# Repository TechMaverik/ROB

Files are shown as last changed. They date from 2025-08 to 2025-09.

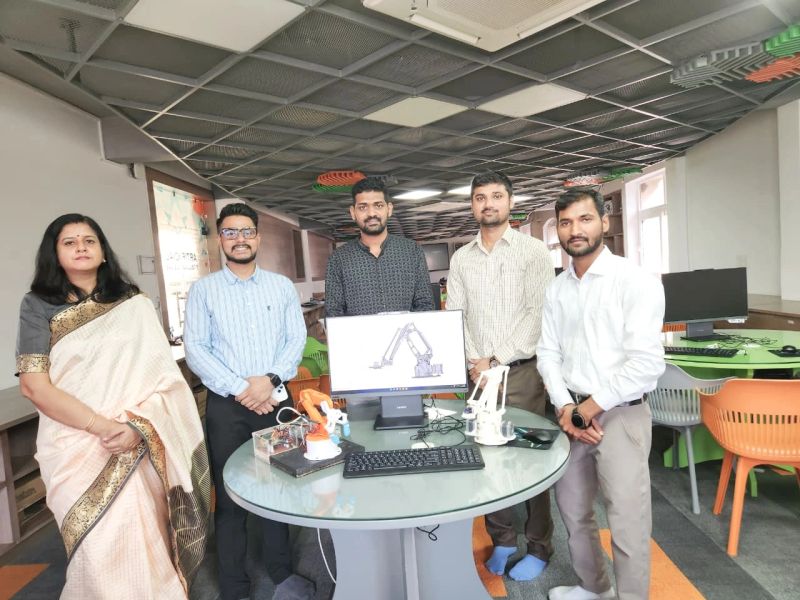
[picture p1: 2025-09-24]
static/Team.jpeg

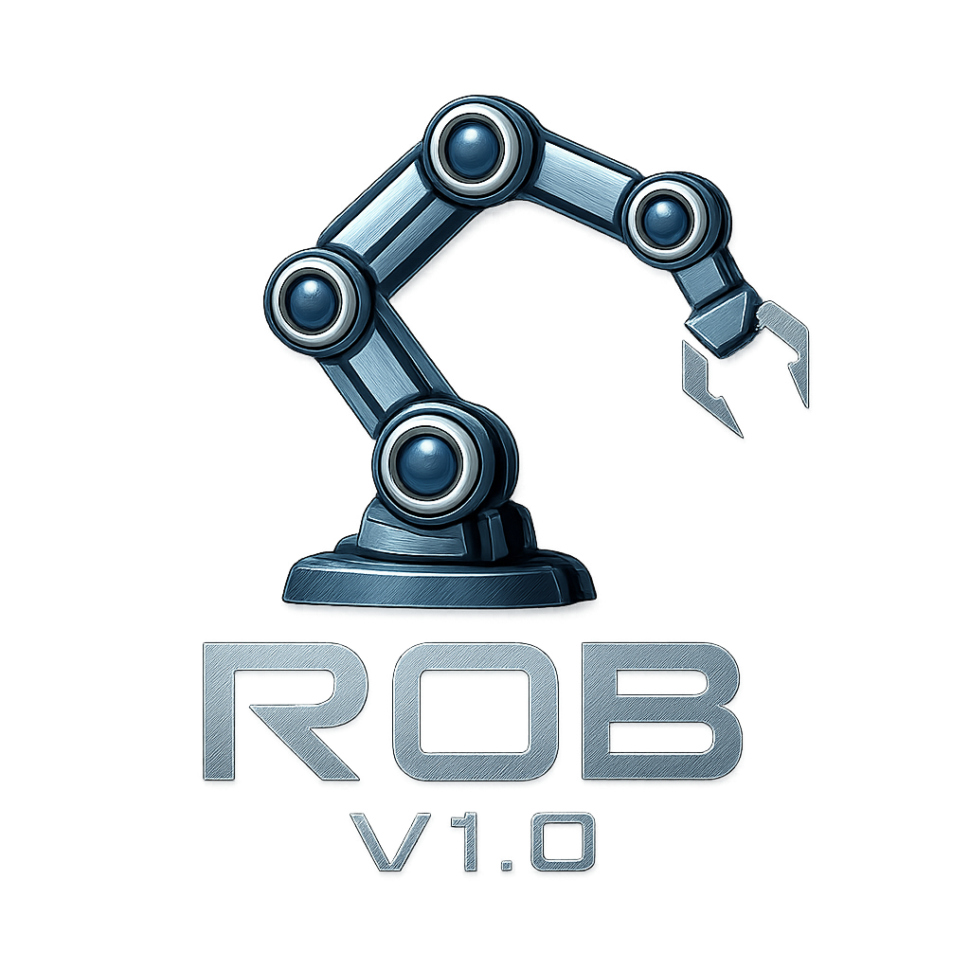
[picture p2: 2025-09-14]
static/rob.png

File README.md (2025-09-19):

# ROB - Robotics On Board
<image src="static/studio.png" height=300px width=300px></image>

The project ROB is a robotic arm developed with in-house software, hardware assembly, and custom PCB design. ROB-Studio is the software used to interact with the robot.  
Version 1.0 features a 5-degree-of-freedom robotic arm powered by 6 servo motors, capable of lifting up to 50 g of payload. ROB-Studio is made using the software framework 
called HL-Engine 3, which acts as a middleware to communicate with Hardware and Software.

## ROB version 1.0
## Components Used
1. Servo Motor MG995
2. Servo Motor SG90
3. PCA9685 Servomotor Driver
4. OLED Display 128 x 64
5. ESP32

## Firmware
The baremetal interfacing and control system code is written in Micropython for ESP32

## Procedure of connection of motors and arm pieces
1. Upload the files under Firmware Folder
2. Make sure to provide a valid SSID and Password in the code as per your network connection.
3. Connect the servo motors from channel 0 to channel 5 in order base,shoulder,elbow,wrist-pitch,wrist-yaw,pick.
4. Make sure the servo is set to 90 degress.
5. Adjust the home position according to your requirements.

## Procedure to run the ROB-Studio
1. Install python 3.10 or later version
2. Create a virtual environment called .robot using the command <code>python3 -m venv .robot</code> ( One time )
3. Now run <code> pip3 install -r requirements.txt </code> ( One time )
4. Now run <code> chmod +x ./launcher </code> ( One time )
5. <b>To run the app run ./launcher.py </b>

## Alternative steps to run ROB-Studio
1. Follow the steps till line number 3
2. Now run <code>source .rob/bin/activate </code>
3. Now run <code>python run.py</code>

## ROB Studio
<image src="static/StudioHome.png"></image>
You can control the robor arm by adjusting the slider of each joints and by pressing the Move button. Inorder to record the particular orienttation, one has to adjust the arm and press the Record Button.
<image src="static/StudioRecord.png"></image>
Your recorded operations can be seen under Record and Play tab. You can start running the application by pressing the Play button.
<image src="static/StudioDevice.png"></image>
You can connect the ROB studion to the ROB by entering the IP Address displayed on ROB OLED Display. A sample is shown above.

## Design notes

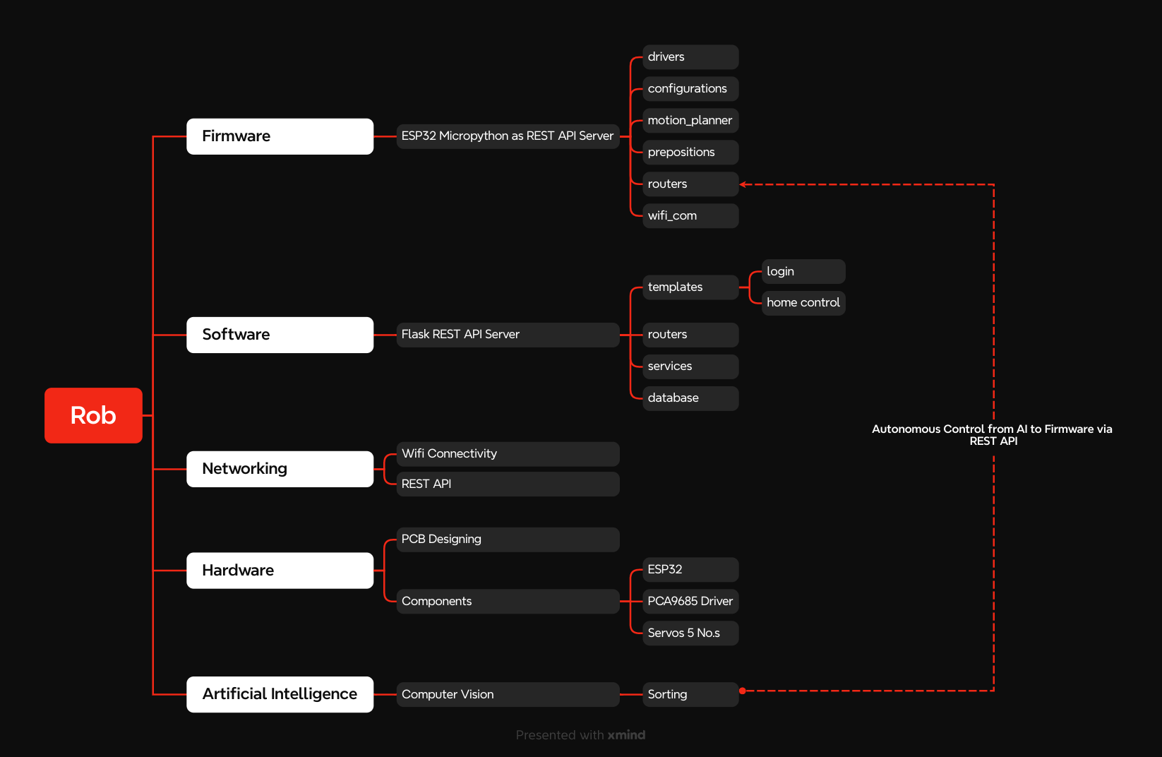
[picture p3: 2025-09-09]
Rob-Architect-Diagram.png

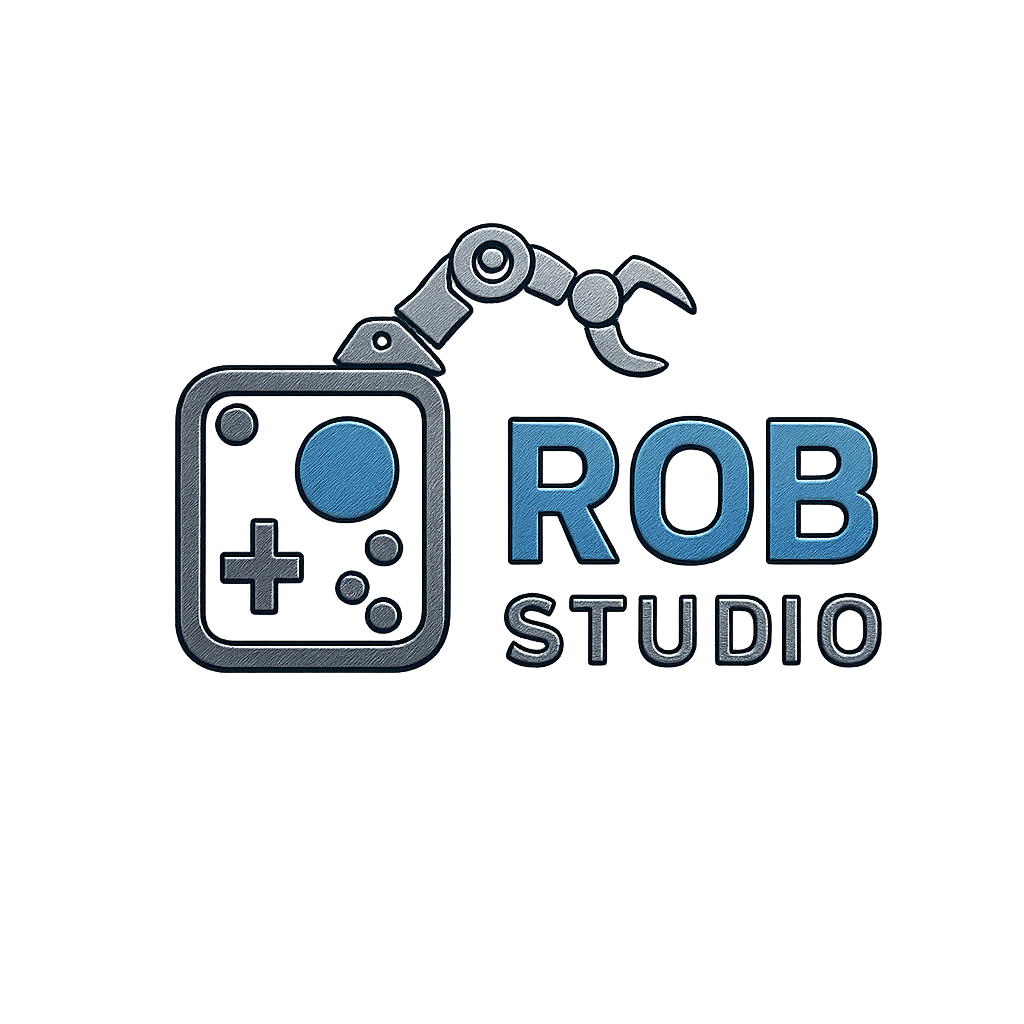
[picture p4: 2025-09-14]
static/studio.png

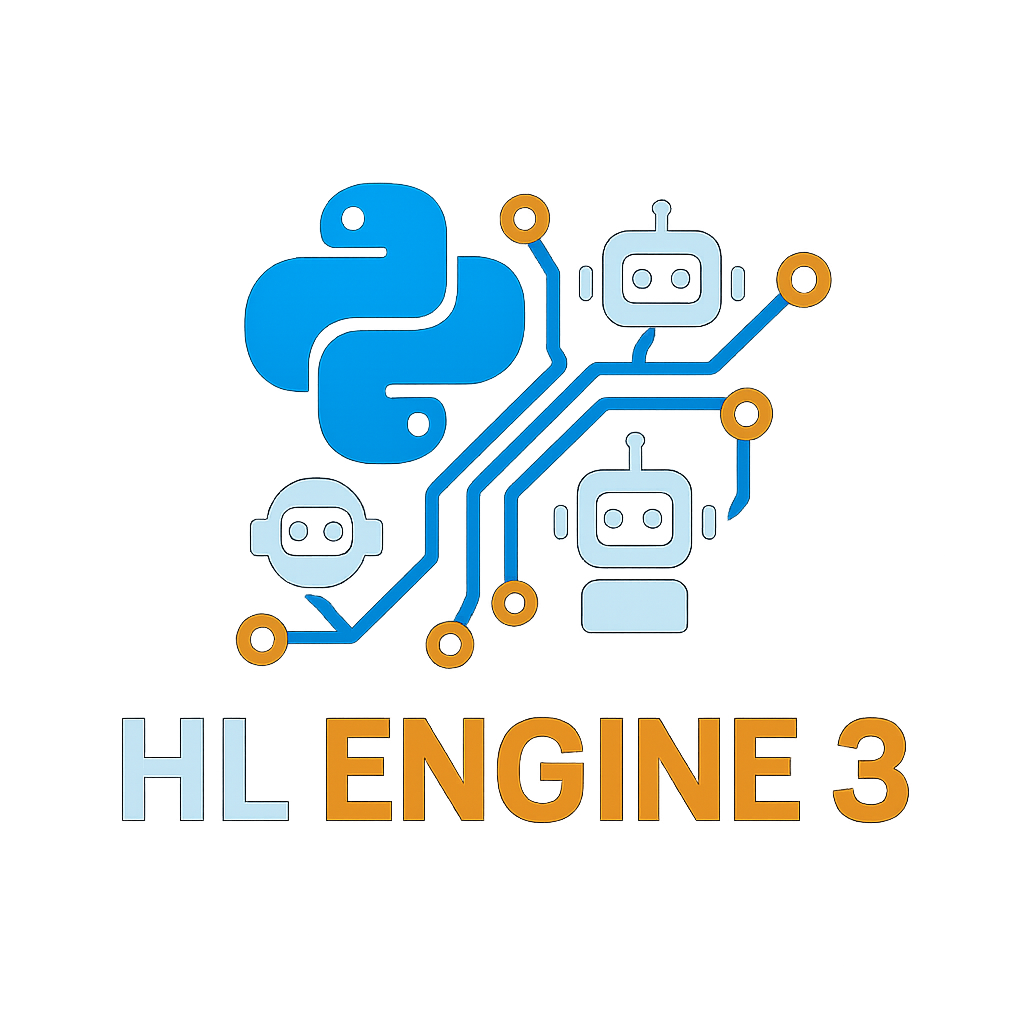
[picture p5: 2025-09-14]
static/hlengine3.png

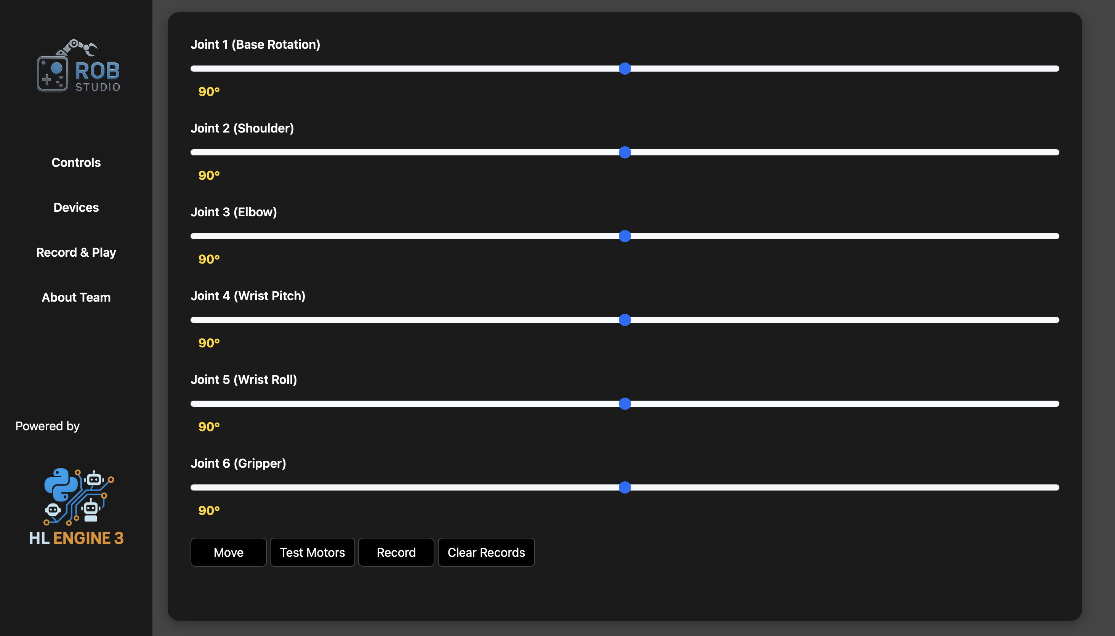
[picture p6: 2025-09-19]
static/StudioHome.png

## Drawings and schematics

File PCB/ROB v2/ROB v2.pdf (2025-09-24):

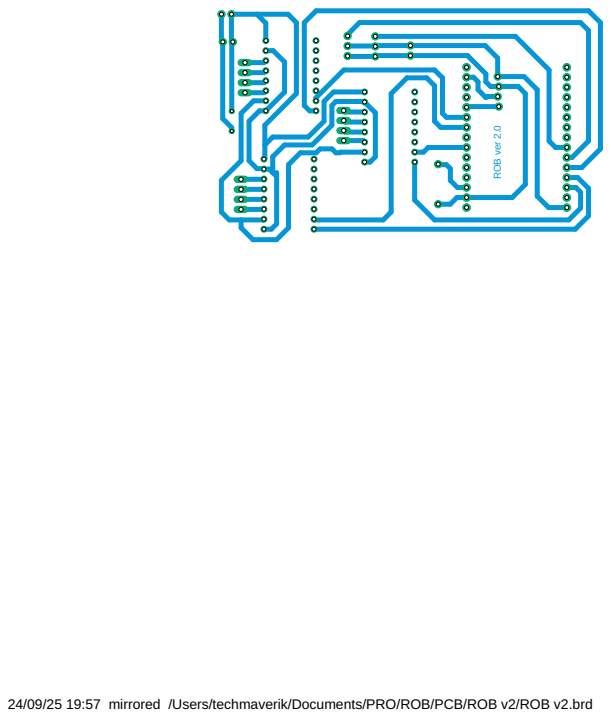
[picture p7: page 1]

24/09/25 19:57 mirrored /Users/techmaverik/Documents/PRO/ROB/PCB/ROB v2/ROB v2.brd

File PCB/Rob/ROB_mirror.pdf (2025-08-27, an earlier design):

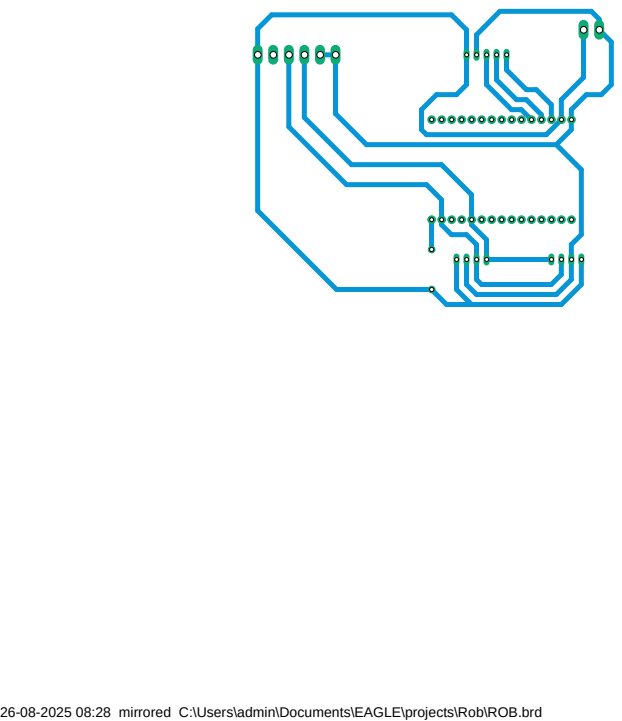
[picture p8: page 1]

26-08-2025 08:28 mirrored C:\Users\admin\Documents\EAGLE\projects\Rob\ROB.brd

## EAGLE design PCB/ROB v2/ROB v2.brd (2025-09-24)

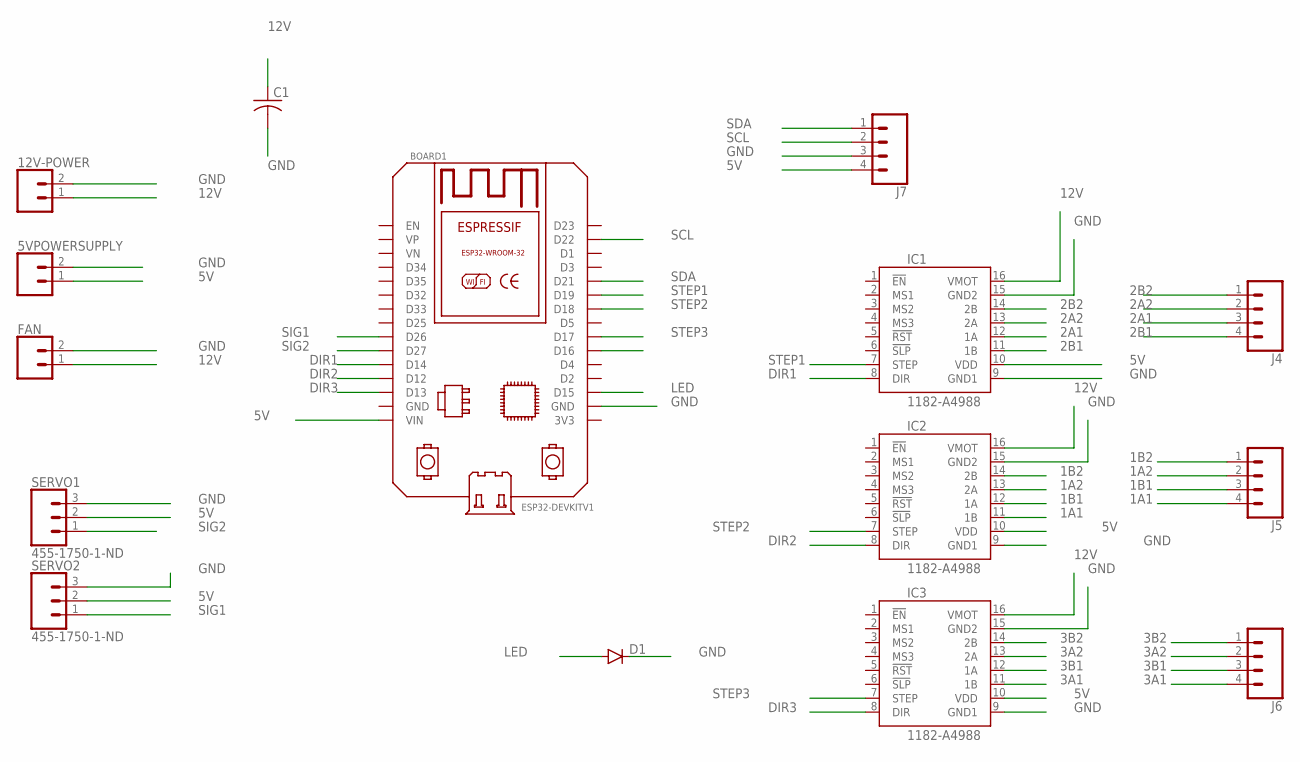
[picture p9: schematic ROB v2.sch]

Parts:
5VPOWERSUPPLY, 12V-POWER: CONN_02; 1X02
BOARD1: ESP32DEVKITV1; ESP32-DEVKITV1
C1: C-US050-075X075; C050-075X075
D1: DIODE; DIODE-1N4001-KIT
FAN: CONN_02; 1X02
IC1, IC2, IC3: 1182-A4988; A4988
J4, J5, J6: CONN_04LONGPADS; 1X04_LONGPADS
J7: CONN_04LOCK; 1X04_LOCK
SERVO1, SERVO2: 455-1750-1-ND; 1X03

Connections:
1A1: IC2.11 (1B), J5.4
1A2: IC2.13 (2A), J5.2
1B1: IC2.12 (1A), J5.3
1B2: IC2.14 (2B), J5.1
2A1: IC1.12 (1A), J4.3
2A2: IC1.13 (2A), J4.2
2B1: IC1.11 (1B), J4.4
2B2: IC1.14 (2B), J4.1
3A1: IC3.11 (1B), J6.4
3A2: IC3.13 (2A), J6.2
3B1: IC3.12 (1A), J6.3
3B2: IC3.14 (2B), J6.1
5V: 5VPOWERSUPPLY.1, BOARD1.VIN, IC1.10 (VDD), IC2.10 (VDD), IC3.10 (VDD), J7.4, SERVO1.2, SERVO2.2
12V: 12V-POWER.1, C1.1, FAN.1, IC1.16 (VMOT), IC2.16 (VMOT), IC3.16 (VMOT)
DIR1: BOARD1.D14, IC1.8 (DIR)
DIR2: BOARD1.D12, IC2.8 (DIR)
DIR3: BOARD1.D13, IC3.8 (DIR)
GND: 5VPOWERSUPPLY.2, 12V-POWER.2, BOARD1.GND@1 (GND), C1.2, D1.C, FAN.2, IC1.9 (GND1), IC1.15 (GND2), IC2.9 (GND1), IC2.15 (GND2), IC3.9 (GND1), IC3.15 (GND2), J7.3, SERVO1.3, SERVO2.3
LED: BOARD1.D15, D1.A
SCL: BOARD1.D22, J7.2
SDA: BOARD1.D21, J7.1
SIG1: BOARD1.D26, SERVO2.1
SIG2: BOARD1.D27, SERVO1.1
STEP1: BOARD1.D19, IC1.7 (STEP)
STEP2: BOARD1.D18, IC2.7 (STEP)
STEP3: BOARD1.D17, IC3.7 (STEP)

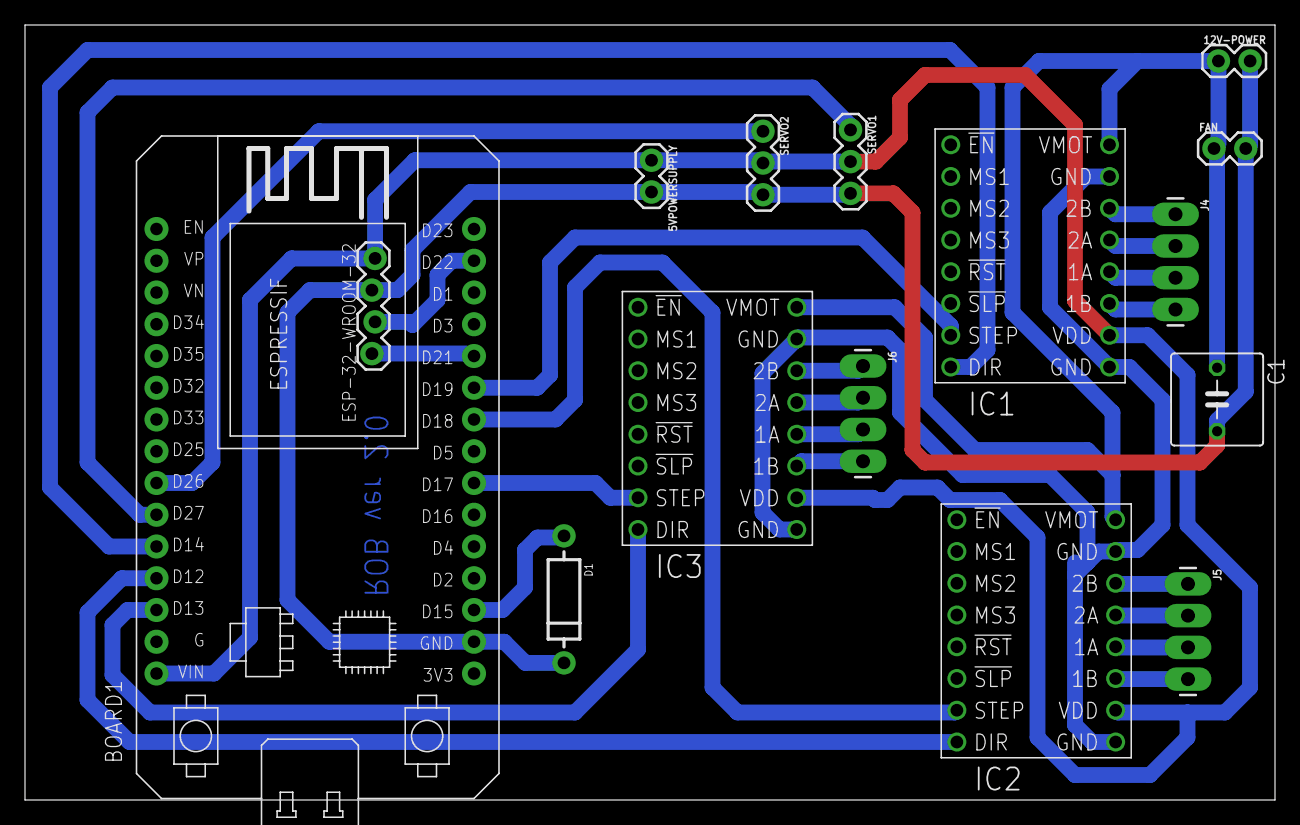
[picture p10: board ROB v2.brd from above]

Board: 2 copper layers, 100.0 x 62.0 mm, 15 parts (0 on the bottom side), 26 nets.

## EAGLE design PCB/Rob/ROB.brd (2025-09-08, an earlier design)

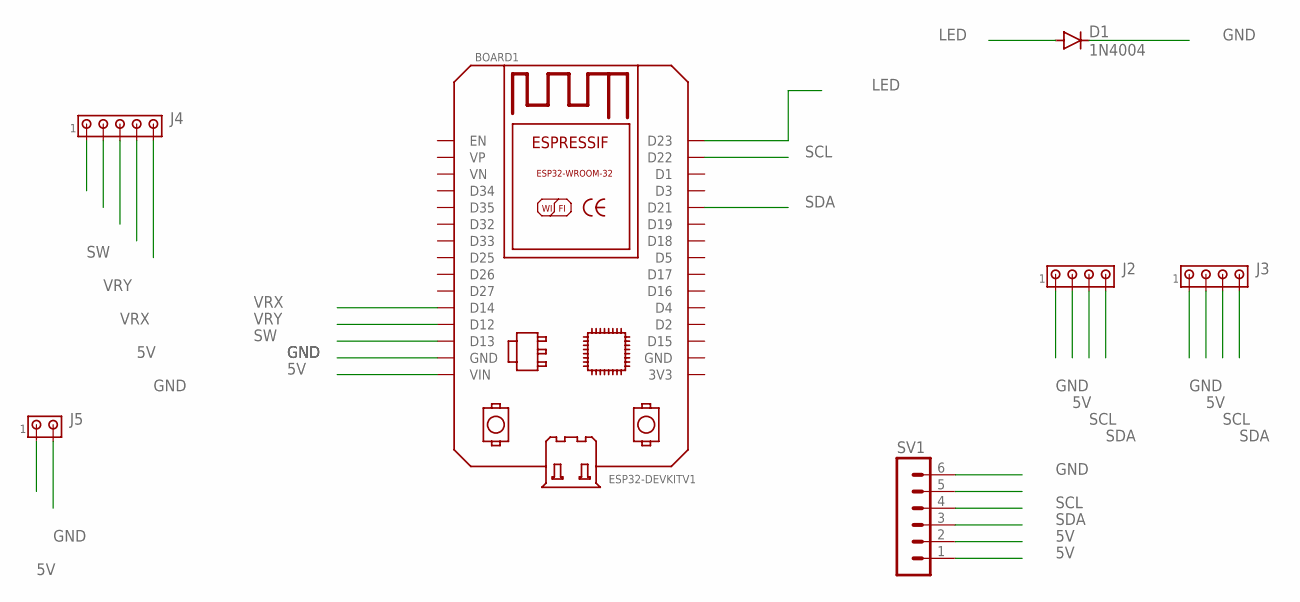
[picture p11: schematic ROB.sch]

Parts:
BOARD1: ESP32DEVKITV1; ESP32-DEVKITV1
D1: 1N4004; DO41-10
J2, J3: MTA04-100; 10X04MTA
J4: MTA05-100; 10X05MTA
J5: MTA02-156; 1X2MTA
SV1: MA06-1

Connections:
5V: BOARD1.VIN, J2.2, J3.2, J4.4, J5.1, SV1.1, SV1.2
GND: BOARD1.GND, D1.C, J2.1, J3.1, J4.5, J5.2, SV1.6
LED: BOARD1.D23, D1.A
SCL: BOARD1.D22, J2.3, J3.3, SV1.4
SDA: BOARD1.D21, J2.4, J3.4, SV1.3
SW: BOARD1.D13, J4.1
VRX: BOARD1.D14, J4.3
VRY: BOARD1.D12, J4.2

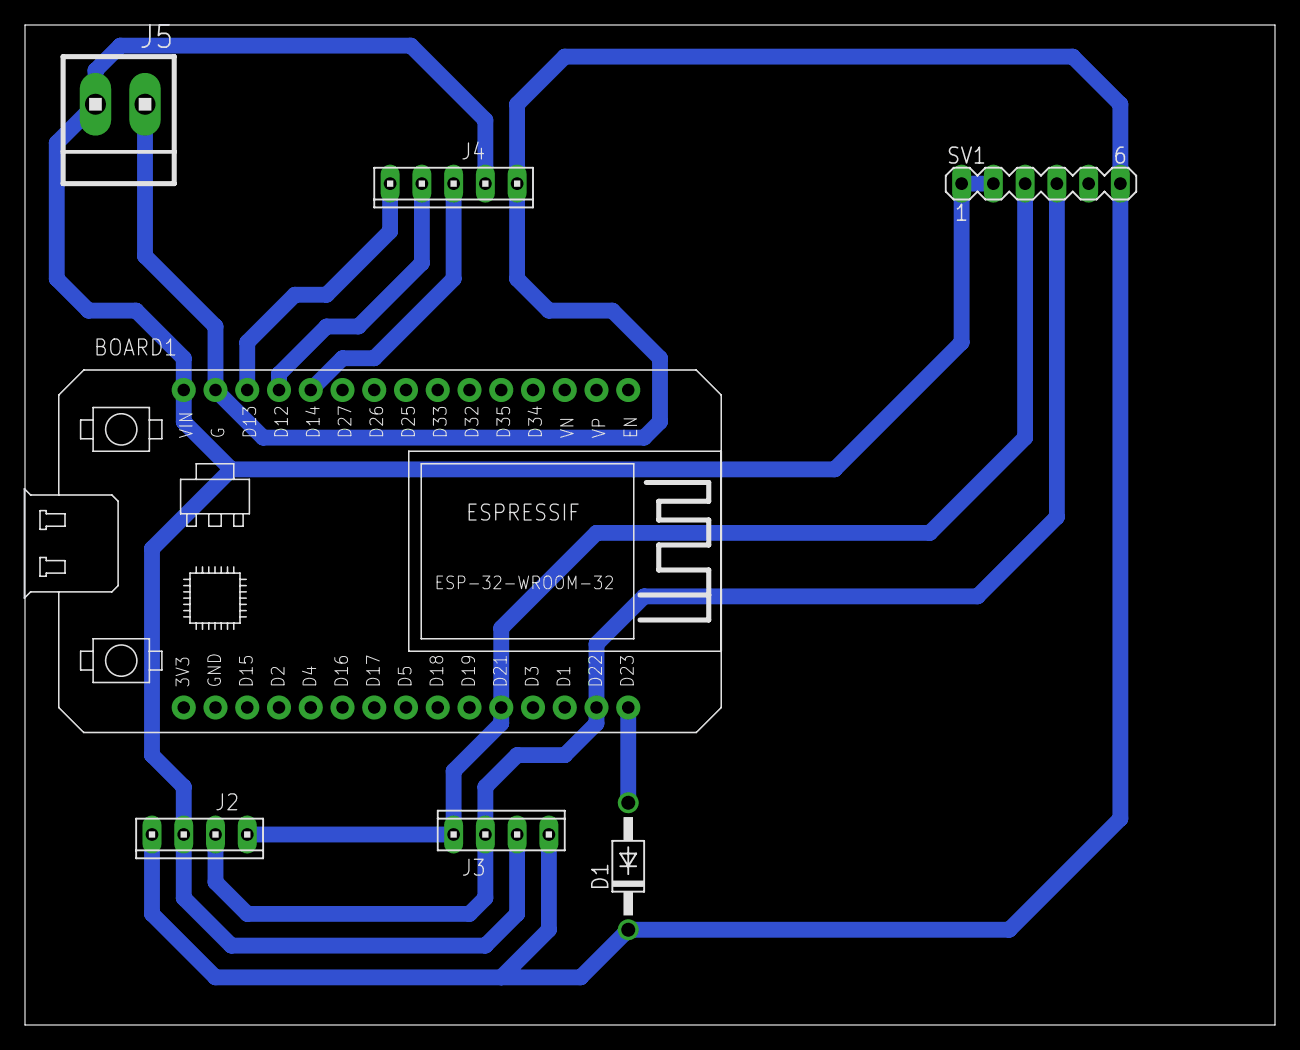
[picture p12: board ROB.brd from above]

Board: 2 copper layers, 100.0 x 80.0 mm, 7 parts (0 on the bottom side), 8 nets.

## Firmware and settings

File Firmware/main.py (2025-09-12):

import socket
import ujson
import time
import configurations
from wifi_con import WifiCon
from motion_planner import MotionPlanner

WifiCon().connect()
MotionPlanner().set_default_position()


def parse_json_from_request(request):
    try:
        body = request.split("\r\n\r\n", 1)[1].strip()
        return ujson.loads(body)
    except:
        return None


addr = socket.getaddrinfo("0.0.0.0", 80)[0][-1]
s = socket.socket()
s.bind(addr)
s.listen(1)

while True:
    cl, addr = s.accept()
    request = cl.recv(2048).decode()
    try:
        method, path, _ = request.split(" ", 2)
    except ValueError:
        continue

    if method == "POST" and path == "/rob/move/":
        data = parse_json_from_request(request)
        if data:
            response_data = {
                "success": True,
                "received": data,
                "message": "Move command received and processed",
            }
            response = configurations.OK_HEADER + ujson.dumps(response_data)
            MotionPlanner().software_feedback_control_system(final_position=data)
        else:
            response = configurations.BAD_HEADER + ujson.dumps(
                {"error": "Invalid JSON"}
            )

    elif method == "GET" and path == "/":       
        response_data = {
            "device": "Rob Robotic Arm",
            "version": 1.0,
            "status": "Ready",
        }
        response = configurations.OK_HEADER + ujson.dumps(response_data)
        
    else:
        response = configurations.BAD_HEADER + ujson.dumps(
            {"error": "Unsupported method or path"}
        )

    cl.send(response)
    cl.close()

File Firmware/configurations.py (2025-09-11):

"configurations.py"

SSID = "Ai Lab"
PSW = "Welc0me@123"
CHANNEL_1 = 0
CHANNEL_2 = 1
CHANNEL_3 = 2
CHANNEL_4 = 3
CHANNEL_5 = 4
CHANNEL_6 = 5
DEFAULT_ANGLE = 90
SPEED = 1
OK_HEADER = "HTTP/1.1 200 OK\r\nContent-Type: application/json\r\n\r\n"
BAD_HEADER = "HTTP/1.1 400 Bad Request\r\nContent-Type: application/json\r\n\r\n"
soft_feedback = {
    "base": 90,
    "shoulder": 90,
    "elbow": 90,
    "wrist": 90,
    "end_effector": 90,
    "pick": 90,
}

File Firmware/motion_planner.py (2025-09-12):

from machine import I2C, Pin
from drivers.pca9685 import PCA9685
from drivers.servo import Servos
import configurations
import time


class MotionPlanner:

    def __init__(self):
        self.i2c = I2C(0, scl=Pin(22), sda=Pin(21))
        self.pca = PCA9685(self.i2c)
        self.pca.freq(50)
        self.servos = Servos(self.i2c)
        self.channel_1 = configurations.CHANNEL_1
        self.channel_2 = configurations.CHANNEL_2
        self.channel_3 = configurations.CHANNEL_3
        self.channel_4 = configurations.CHANNEL_4
        self.channel_5 = configurations.CHANNEL_5
        self.channel_6 = configurations.CHANNEL_6
        self.default_angle = configurations.DEFAULT_ANGLE
        self.feedback = configurations.soft_feedback
        self.speed = configurations.SPEED

    def set_default_position(self):
        """Set all servos to their default position."""
        self.servos.position(index=self.channel_1, degrees=self.default_angle)
        self.feedback["base"] = self.default_angle
        time.sleep(0.25)
        self.servos.position(index=self.channel_2, degrees=self.default_angle)
        self.feedback["shoulder"] = self.default_angle
        time.sleep(0.25)
        self.servos.position(index=self.channel_3, degrees=self.default_angle)
        self.feedback["elbow"] = self.default_angle
        time.sleep(0.25)
        self.servos.position(index=self.channel_4, degrees=self.default_angle)
        self.feedback["wrist"] = self.default_angle
        time.sleep(0.25)
        self.servos.position(index=self.channel_5, degrees=self.default_angle)
        self.feedback["end_effector"] = self.default_angle
        time.sleep(0.25)
        self.servos.position(index=self.channel_6, degrees=self.default_angle)
        self.feedback["pick"] = self.default_angle
        time.sleep(0.25)
        return self.feedback

    def sweep(self, channel: int, arm: str) -> bool:
        """Sweep a servo from 0 to 180 degrees and back to default position."""
        for angle in range(self.default_angle, 181, self.speed):
            self.servos.position(index=channel, degrees=angle)
            self.feedback[arm] = angle
            time.sleep(0.10)
        for angle in range(181, self.default_angle, -self.speed):
            self.servos.position(index=channel, degrees=angle)
            self.feedback[arm] = angle
            time.sleep(0.10)
        for angle in range(self.default_angle, 0, -self.speed):
            self.servos.position(index=channel, degrees=angle)
            self.feedback[arm] = angle
            time.sleep(0.10)
        for angle in range(0, self.default_angle, self.speed):
            self.servos.position(index=channel, degrees=angle)
            self.feedback[arm] = angle
            time.sleep(0.10)
        return True

    def move(self, channel: int, up_down_logic: bool, steps: int, arm: str) -> bool:
        """Move the Robotic Arm.

        Args:
            channel (int): select channel
            up_down_logic (bool): up or down logic which is True or False
            steps (int): number of steps to move
            arm (str): motor name

        Returns:
            bool: Boolean value indicating success
        """
        current_position = self.feedback[arm]
        to_positon = current_position  # Initialize to current position

        if up_down_logic is True:
            for step in range(1, steps, 1):
                to_positon = current_position + step
                self.servos.position(index=channel, degrees=to_positon)
                time.sleep(0.05)
                # print(step, to_positon)
            self.feedback[arm] = to_positon
            return True

        if up_down_logic is False:
            for step in range(1, steps, 1):
                to_positon = current_position - step
                self.servos.position(index=channel, degrees=to_positon)
                time.sleep(0.05)
                # print(step, to_positon)
            self.feedback[arm] = to_positon
            return True

    def difference_engine(self, final_position: dict) -> dict:
        """Calculate the difference between current and final positions."""
        base_diff = int(final_position["base"]) - int(self.feedback["base"])
        shoulder_diff = int(final_position["shoulder"]) - int(self.feedback["shoulder"])
        elbow_diff = int(final_position["elbow"]) - int(self.feedback["elbow"])
        wrist_diff = int(final_position["wrist"]) - int(self.feedback["wrist"])
        end_effector_diff = (
            int(final_position["end_effector"]) - int(self.feedback["end_effector"])
        )
        pick_diff = int(final_position["pick"]) - int(self.feedback["pick"])
        return {
            "base_diff": base_diff,
            "shoulder_diff": shoulder_diff,
            "elbow_diff": elbow_diff,
            "wrist_diff": wrist_diff,
            "end_effector_diff": end_effector_diff,
            "pick_diff": pick_diff,
        }

    def software_feedback_control_system(self, final_position: dict) -> dict:
        """Feedback control system to move the arm to the final position.

        Args:
            final_position (dict): final position dictionary
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

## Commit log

2025-08-27 PCB Designing
    [ROB.brd, ROB.sch]
2025-09-08 pcb files
    [ROB.brd, ROB.sch]
2025-09-15 added new submit button
2025-09-17 removed home position button
2025-09-21 version 2 pcb design updates
    [ROB v2.brd, ROB v2.sch]
2025-09-24 updated schematics and board
    [ROB v2 v1.brd, ROB v2.brd, ROB v2.sch]

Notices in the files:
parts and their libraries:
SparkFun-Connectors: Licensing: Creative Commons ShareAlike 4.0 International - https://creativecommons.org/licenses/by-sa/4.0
